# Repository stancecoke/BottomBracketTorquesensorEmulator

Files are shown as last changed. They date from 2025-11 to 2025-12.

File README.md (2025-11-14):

# BottomBracketTorquesensorEmulator

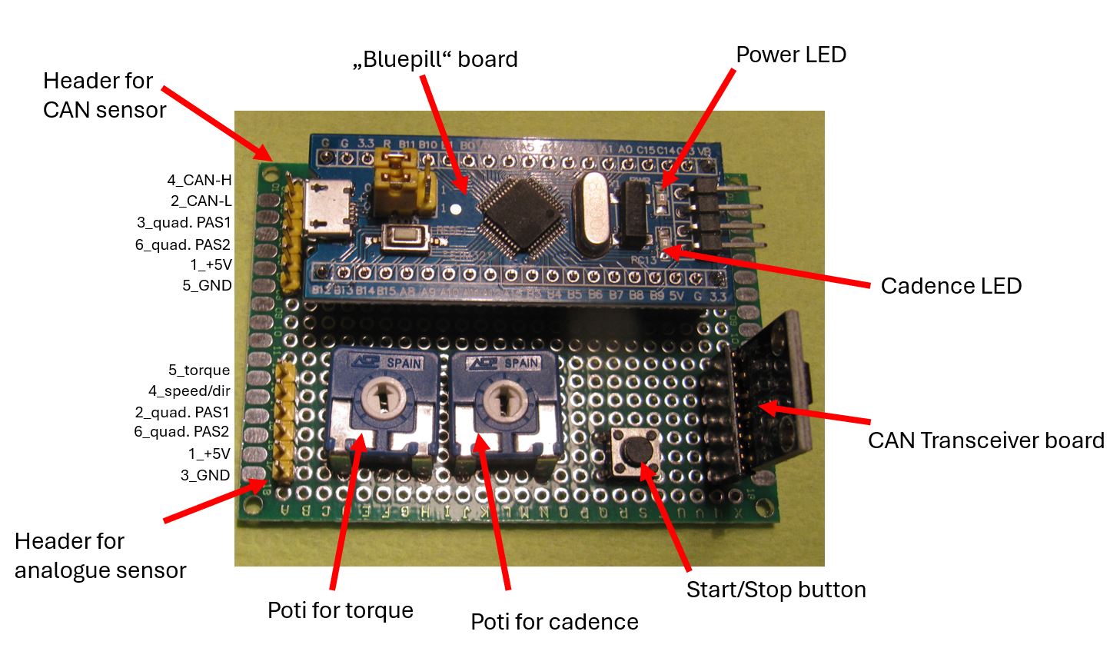
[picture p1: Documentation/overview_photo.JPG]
  

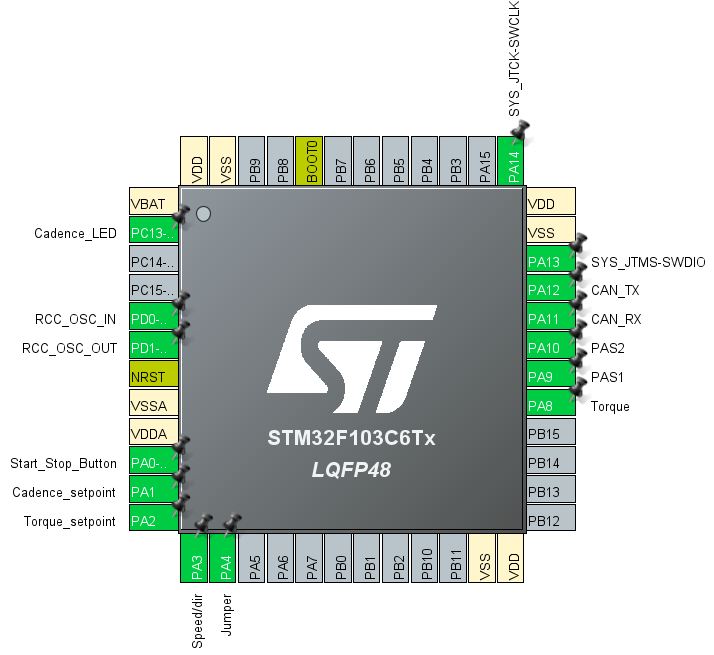
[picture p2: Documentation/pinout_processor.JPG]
pinout
  

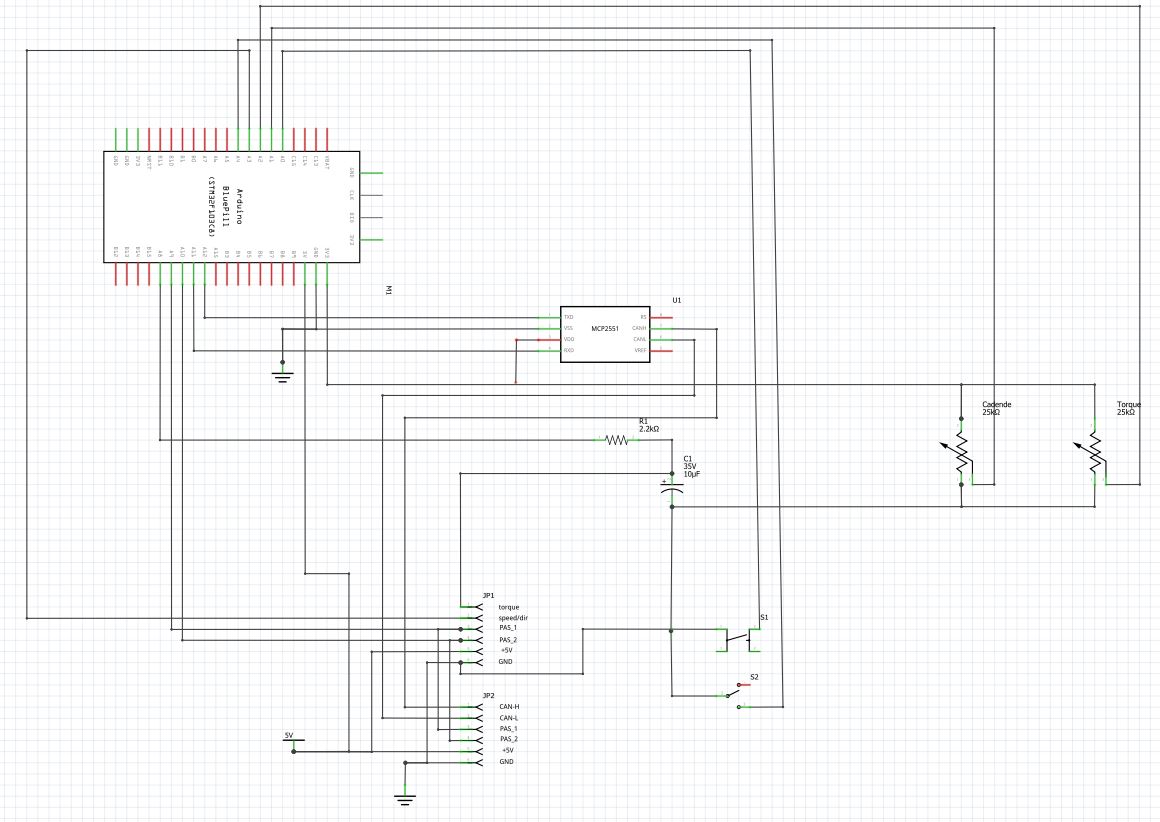
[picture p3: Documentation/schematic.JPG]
  
  
  This program is free software: you can redistribute it and/or modify it under the terms of the GNU General Public License as published by the Free Software Foundation, either version 3 of the License, or (at your option) any later version.

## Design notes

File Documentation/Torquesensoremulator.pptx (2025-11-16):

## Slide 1

Kadenz LED

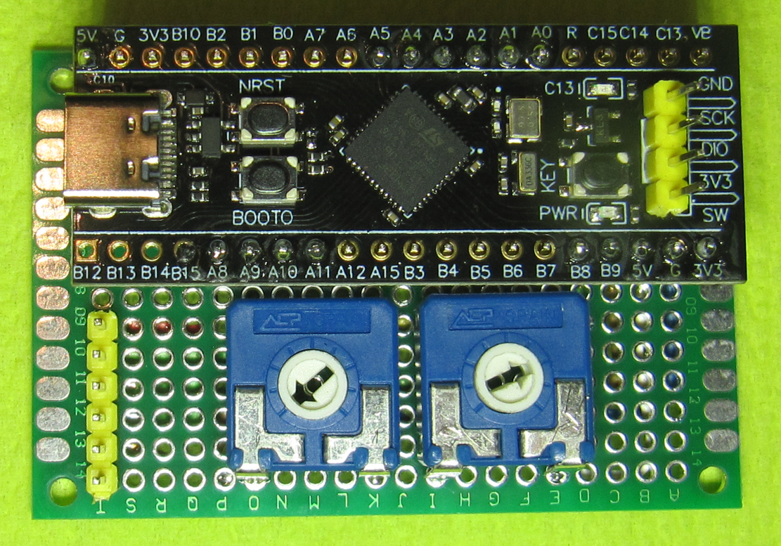
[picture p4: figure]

USB-C für digitatle Ausgabe der Parameter

Start/Stop Button

6_quad. PAS2

2_speed/dir

3_torque

Power LED

4_quad. PAS1

5_+5V

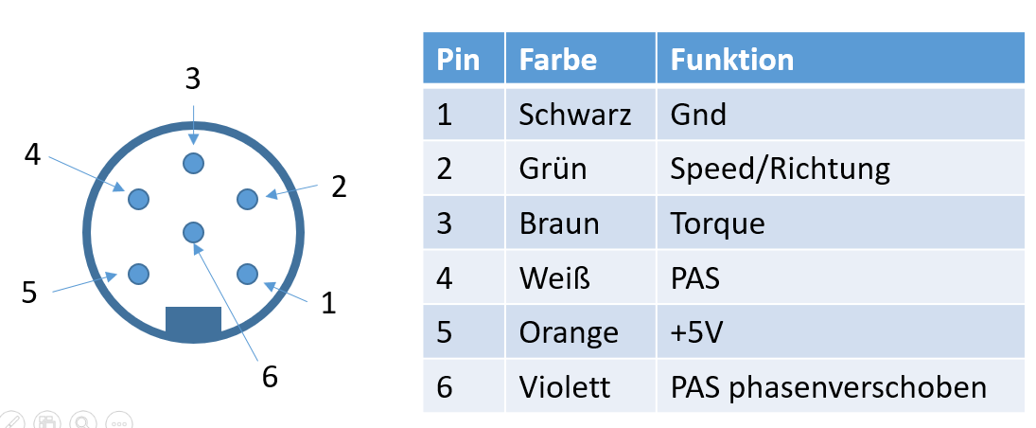
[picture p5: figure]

1_GND

Poti für Torque

Poti für Kadenz

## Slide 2

Power LED

Header for
CAN sensor

„Bluepill“ board

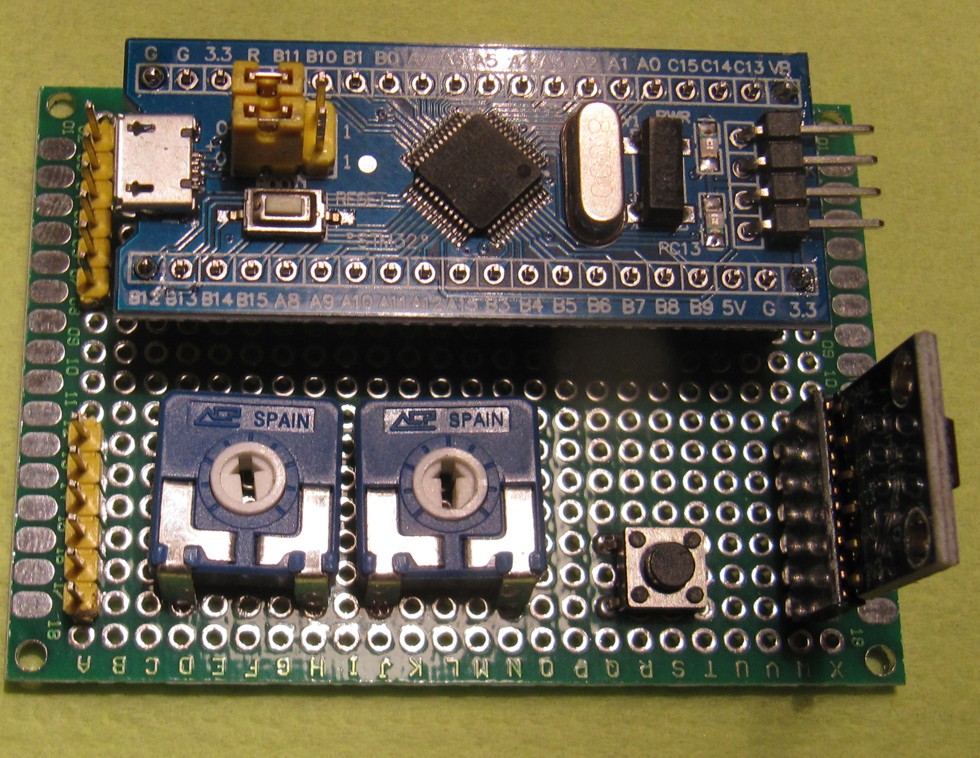
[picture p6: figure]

3_quad. PAS1

4_CAN-H

2_CAN-L

6_quad. PAS2

5_GND

1_+5V

Cadence LED

2_quad. PAS1

4_speed/dir

5_torque

6_quad. PAS2

1_+5V

CAN Transceiver board

3_GND

Header for
analogue sensor

Start/Stop button

Poti for torque

Poti for cadence

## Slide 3

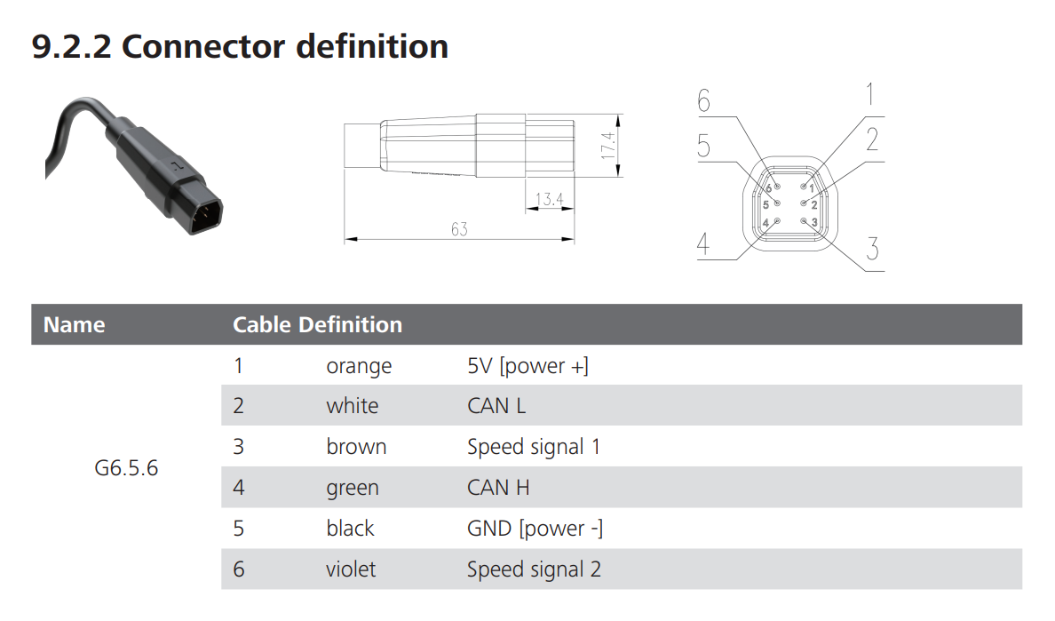
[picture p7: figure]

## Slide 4

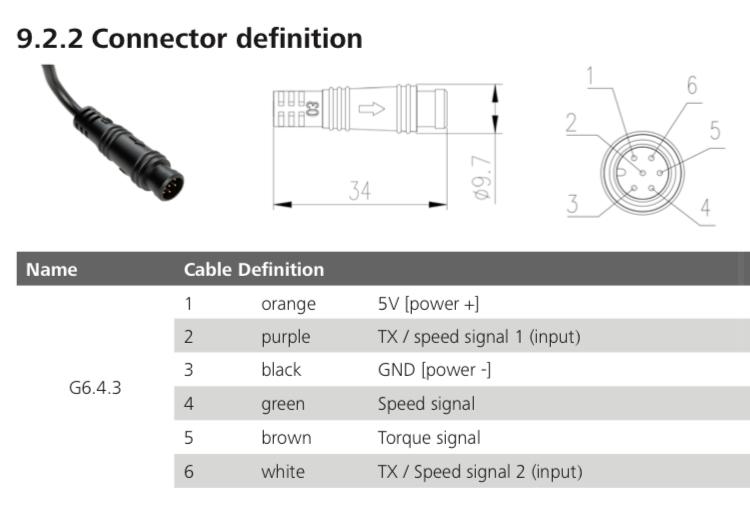
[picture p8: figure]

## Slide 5

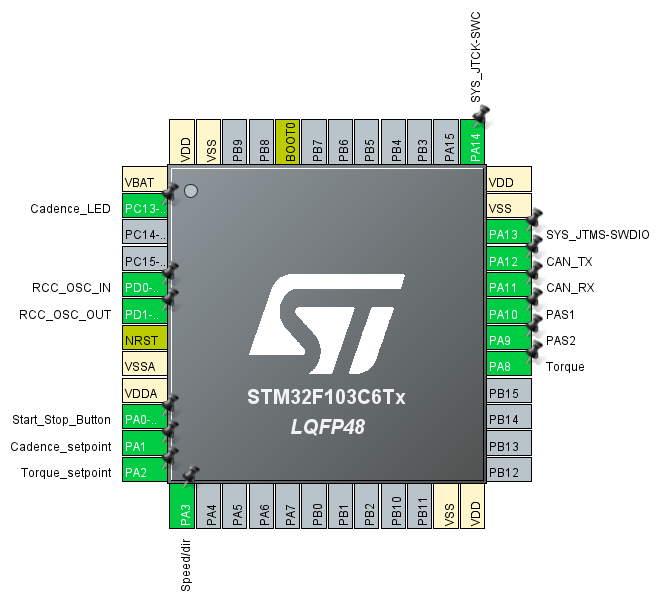
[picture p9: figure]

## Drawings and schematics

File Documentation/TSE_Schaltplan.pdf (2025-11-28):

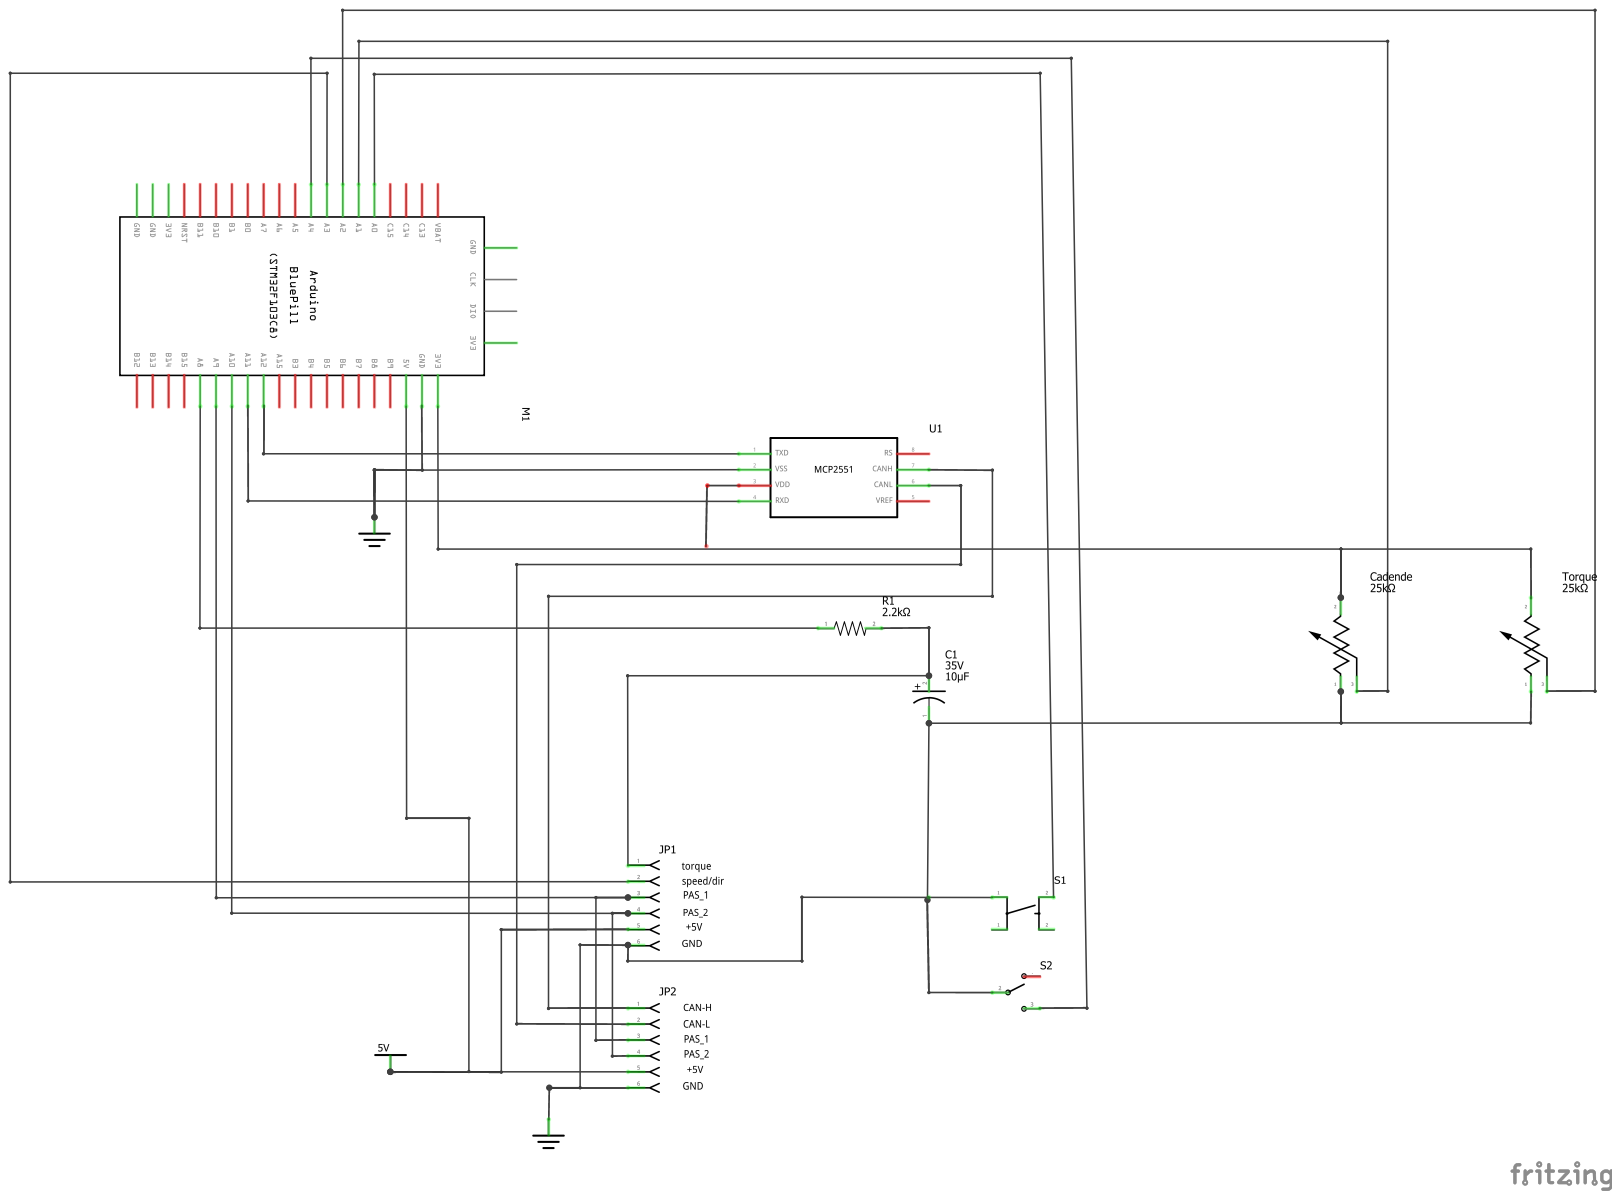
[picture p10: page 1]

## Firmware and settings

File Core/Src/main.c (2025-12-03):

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
/* Includes ------------------------------------------------------------------*/
#include "main.h"

/* USER CODE BEGIN Includes */

#include "stdbool.h"
#include "stdio.h"

/* USER CODE END Includes */

ADC_HandleTypeDef hadc1;
DMA_HandleTypeDef hdma_adc1;

CAN_HandleTypeDef hcan;

TIM_HandleTypeDef htim1;
TIM_HandleTypeDef htim3;

UART_HandleTypeDef huart1;

/* USER CODE BEGIN PV */
uint16_t tim1_counter=0;
uint16_t idle_voltage=910;
uint16_t PAS_counter=0;
uint16_t Torque_setpoint=0;
uint16_t Torque_mV=700;
uint16_t Cadence_rpm=30;
uint16_t PAS_setpoint=16000;
uint16_t DutyCycle=50;
uint8_t half_revolution_counter=0;
uint8_t sine_curve[16]={
		49,
		97,
		142,
		181,
		212,
		236,
		251,
		255,
		251,
		236,
		212,
		181,
		142,
		97,
		49,
		0
};
char USB_Tx_Buffer[64];
uint16_t Tx_len;
bool ButtonState=true;
bool JumperState=true;
bool ButtonState_old=true;
bool OutputActive=false;
bool Q_PAS1_old=0;
bool Q_PAS2_old=0;
bool Q_PAS1state=0;
bool Q_PAS2state=0;
uint16_t debounce;
uint16_t ADC_VAL[2];

char UART_TX_Buffer[100];
char UART_RX_Buffer[100];

CAN_TxHeaderTypeDef   TxHeader;
CAN_RxHeaderTypeDef   RxHeader;
uint32_t              TxMailbox;
uint8_t 			  TxData[8];
/* USER CODE END PV */

void SystemClock_Config(void);
static void MX_GPIO_Init(void);
static void MX_DMA_Init(void);
static void MX_ADC1_Init(void);
static void MX_CAN_Init(void);
static void MX_USART1_UART_Init(void);
static void MX_TIM1_Init(void);
static void MX_TIM3_Init(void);
/* USER CODE BEGIN PFP */
int32_t map (int32_t x, int32_t in_min, int32_t in_max, int32_t out_min, int32_t out_max);
void update_torque (void);

/**
  * @brief  The application entry point.
  * @retval int
  */
int main(void)
{
  /* MCU Configuration--------------------------------------------------------*/

  /* Reset of all peripherals, Initializes the Flash interface and the Systick. */
  HAL_Init();

  /* Configure the system clock */
  SystemClock_Config();

  /* Initialize all configured peripherals */
  MX_GPIO_Init();
  MX_DMA_Init();
  MX_ADC1_Init();
  MX_CAN_Init();
  //MX_USART1_UART_Init();
  MX_TIM1_Init();
  MX_TIM3_Init();
  /* USER CODE BEGIN 2 */
  if(HAL_TIM_Base_Start_IT(&htim1) != HAL_OK)
      {
        /* Counter Enable Error */
        Error_Handler();
      }
    HAL_TIM_PWM_Start(&htim1, TIM_CHANNEL_1);
      TIM1->CCR1 = Torque_setpoint;
    HAL_TIM_Base_Start(&htim3);

    HAL_ADC_Start_DMA(&hadc1, (uint32_t*)ADC_VAL, 2);
  /* USER CODE END 2 */

  /* Infinite loop */
  /* USER CODE BEGIN WHILE */
  while (1)
  {

	  ButtonState=HAL_GPIO_ReadPin (UserButton_GPIO_Port, UserButton_Pin);
	  JumperState=HAL_GPIO_ReadPin (Jumper_GPIO_Port, Jumper_Pin);
	  if(ButtonState!=ButtonState_old&&debounce>50){
		  ButtonState_old=ButtonState;
		  debounce =0;
		  if(ButtonState){
			  if(OutputActive)OutputActive=false;
			  else OutputActive=true;
		  }
	  }
	  if(tim1_counter>8000){


		  tim1_counter=0;
		  sprintf(USB_Tx_Buffer, "%d, %d, %d, %d, %d, %d, %d\r\n",OutputActive, ADC_VAL[0],ADC_VAL[1],Torque_mV,PAS_setpoint,Cadence_rpm,DutyCycle);
		  Tx_len = strlen(USB_Tx_Buffer);

		  if(JumperState){ //send CAN message only in torquesensor mode
			TxData[0] = (Torque_mV)&0xFF; //torque LSB
			TxData[1] = (Torque_mV>>8)&0xFF; //torque MSB
			TxData[2] = Cadence_rpm;
			TxData[3] = 0x01; //progressive byte?!

			if (HAL_CAN_AddTxMessage(&hcan, &TxHeader, TxData, &TxMailbox) != HAL_OK)
			  {
			   // Transmission request Error
			   //Error_Handler();
			  }
		  }
		  //CDC_Transmit_FS((uint8_t*) USB_Tx_Buffer, Tx_len);
	  }
		if (OutputActive) {
			PAS_setpoint = map (ADC_VAL[0], 0, 4095, 1900, 500);
			Cadence_rpm = 64000/PAS_setpoint;
			Torque_setpoint = map (ADC_VAL[1], 0, 4095, idle_voltage, 3600);
			Torque_mV = map (Torque_setpoint, 0, 3600, 0, 3300);
			//TIM1->CCR1 = Torque_setpoint;
			//PAS1 signal generation
			if (PAS_counter > PAS_setpoint>>1) Q_PAS1state=1;
			else Q_PAS1state=0;

			if(Q_PAS1state&&Q_PAS1state!=Q_PAS1_old)
			{
				HAL_GPIO_WritePin(LED_GPIO_Port, LED_Pin, 1);
				HAL_GPIO_WritePin(LED2_GPIO_Port, LED2_Pin, 1);
				HAL_GPIO_WritePin(Q_PAS1_GPIO_Port, Q_PAS1_Pin, 1);
			}
			if (!Q_PAS1state&&Q_PAS1state!=Q_PAS1_old) {
				HAL_GPIO_WritePin(LED_GPIO_Port, LED_Pin, 0);
				HAL_GPIO_WritePin(LED2_GPIO_Port, LED2_Pin, 0);
				HAL_GPIO_WritePin(Q_PAS1_GPIO_Port, Q_PAS1_Pin, 0);
			}
			//reset counter
			if (PAS_counter > PAS_setpoint)PAS_counter = 0;

			//PAS2 signal generation
			if (PAS_counter > PAS_setpoint>>2&&PAS_counter < (PAS_setpoint*3)>>2) Q_PAS2state=1;
			else Q_PAS2state=0;

			if(Q_PAS2state&&Q_PAS2state!=Q_PAS2_old)
			{
				update_torque();
				HAL_GPIO_WritePin(Q_PAS2_GPIO_Port, Q_PAS2_Pin, 1);
			}
			if(!Q_PAS2state&&Q_PAS2state!=Q_PAS2_old) {
				update_torque();
				HAL_GPIO_WritePin(Q_PAS2_GPIO_Port, Q_PAS2_Pin, 0);

			}
			//speed/direction signal generation
			if(Q_PAS2state!=Q_PAS2_old||Q_PAS1state!=Q_PAS1_old){

				HAL_GPIO_TogglePin(PAS_signal_GPIO_Port, PAS_signal_Pin);
				}
			Q_PAS1_old= Q_PAS1state;
			Q_PAS2_old= Q_PAS2state;


		}
		else{

			HAL_GPIO_WritePin(LED_GPIO_Port, LED_Pin, 0);
			HAL_GPIO_WritePin(PAS_signal_GPIO_Port, PAS_signal_Pin, 0);
			Cadence_rpm=0;
			if(JumperState){
				Torque_mV=700;
				TIM1->CCR1 = idle_voltage;
			}
			else {
				Torque_mV=0;
				TIM1->CCR1 = 0;
			}
		}
    /* USER CODE END WHILE */

    /* USER CODE BEGIN 3 */
  }
  /* USER CODE END 3 */
}

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
/* USER CODE BEGIN 4 */
int32_t map (int32_t x, int32_t in_min, int32_t in_max, int32_t out_min, int32_t out_max)
{
  // if input is smaller/bigger than expected return the min/max out ranges value
  if (x < in_min)
    return out_min;
  else if (x > in_max)
    return out_max;

  // map the input to the output range.
  // round up if mapping bigger ranges to smaller ranges
  else  if ((in_max - in_min) > (out_max - out_min))
    return (x - in_min) * (out_max - out_min + 1) / (in_max - in_min + 1) + out_min;
  // round down if mapping smaller ranges to bigger ranges
  else
    return (x - in_min) * (out_max - out_min) / (in_max - in_min) + out_min;
}
void HAL_TIM_PeriodElapsedCallback(TIM_HandleTypeDef *htim)
{
	tim1_counter++;
	PAS_counter++;
	if(debounce<16000)debounce++;
}
void update_torque (void){
	//generate sine-shaped torque signal
	if(JumperState)TIM1->CCR1 = ((sine_curve[half_revolution_counter]*(Torque_setpoint-idle_voltage))>>8)+idle_voltage;
	else TIM1->CCR1 = 0;
	if (half_revolution_counter<16)half_revolution_counter++;
	else half_revolution_counter=0;
}
/* USER CODE END 4 */
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


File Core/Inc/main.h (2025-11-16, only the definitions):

#define Jumper_Pin GPIO_PIN_4
#define Jumper_GPIO_Port GPIOA
#define LED_Pin GPIO_PIN_13
#define LED_GPIO_Port GPIOC
#define LED2_Pin GPIO_PIN_2
#define LED2_GPIO_Port GPIOB
#define UserButton_Pin GPIO_PIN_0
#define UserButton_GPIO_Port GPIOA
#define Cadence_setpoint_Pin GPIO_PIN_1
#define Cadence_setpoint_GPIO_Port GPIOA
#define Torque_setpoint_Pin GPIO_PIN_2
#define Torque_setpoint_GPIO_Port GPIOA
#define PAS_signal_Pin GPIO_PIN_3
#define PAS_signal_GPIO_Port GPIOA
#define Torquesignal_Pin GPIO_PIN_8
#define Torquesignal_GPIO_Port GPIOA
#define Q_PAS2_Pin GPIO_PIN_9
#define Q_PAS2_GPIO_Port GPIOA
#define Q_PAS1_Pin GPIO_PIN_10
#define Q_PAS1_GPIO_Port GPIOA

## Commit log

2025-11-11 Switch to BluePill for CAN support
2025-11-13 scale cadence output to 35-125 rpm
2025-11-14 update documentation
    [TSE.fzz]
2025-11-14 Bugfix in CAN with no CAN connected
    [main.c]
2025-11-15 add Jumper on PA4 for disabling torque output (PAS only function)
2025-11-16 Add LED on PB2 and disable CAN on PAS mode
2025-11-16 Swap PAS1 and PAS2 in documentation
    [TSE.fzz]
2025-11-27 gerenate sine-shaped torque signal WIP
2025-11-27 Torque signal on double frequency, now it's working on UART middrive
2025-11-28 shift voltage level for torque signal
2025-11-28 fix typo in schematic
    [TSE.fzz]
2025-11-29 back to constant torque signal
2025-11-29 torque setpoint init to zero

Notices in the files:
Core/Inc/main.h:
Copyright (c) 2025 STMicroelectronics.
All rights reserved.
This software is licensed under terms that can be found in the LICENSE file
